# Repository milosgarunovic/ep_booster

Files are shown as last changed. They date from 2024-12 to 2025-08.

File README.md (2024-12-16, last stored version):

# ep_booster

KiCad project for EP Booster

---

The idea with this project is to have it in one place, with some "standards" like to view everything
in KiCad and export for manufacturing.

As a bassist, I'm using EP Booster as always on pedal in vintage mode without a boost, and it gives
a nice warmth to my custom bass with jazz pickups, and better thump with my Squier VM Precision with
Wilde P-46 pickup.

What I want to do as a first version is to have the whole thing as a pedal, and then strip away the
parts that are for boost and just leave the vintage part in there so I can put it into my basses,
thus removing one pedal from signal chain.

---

Resources for the project:

- https://www.taydakits.com/instructions/ep-booster/pages/designators-and-components--20
- https://revolutiondeux.blogspot.com/2012/01/xotic-ep-booster.html
- http://toshi.life.coocan.jp/review/en_diy_booster_surface_mount.html
- https://www.amp-fx.de/ep-preamp-booster-en.htm (this one is interesting because it has more caps to change the
  characteristic of the vintage mode)
- https://guitar-electronics.eu/en_US/p/EP-BOOSTER-kit-ULTRA/408

---

From the first source, here's the BOM

## Capacitors (POLYESTER FILM BOX TYPE CAPACITOR)

- C1 47NF 100V 5% POLYESTER FILM BOX TYPE CAPACITOR
- C5 3.3NF 100V 5% POLYESTER FILM BOX TYPE CAPACITOR

## Capacitors (ELECTROLYTIC CAPACITOR 5X11MM)

- C2 10UF 50V ELECTROLYTIC CAPACITOR 5X11MM
- C3 10UF 50V ELECTROLYTIC CAPACITOR 5X11MM (Original)
- C3 0.1UF 50V ELECTROLYTIC CAPACITOR 5X11MM  (Remove more bass)
- C6 10UF 50V ELECTROLYTIC CAPACITOR 5X11MM
- C7 10UF 50V ELECTROLYTIC CAPACITOR 5X11MM
- C8 47UF 25V ELECTROLYTIC CAPACITOR 5X11MM

## Capacitors (ELECTROLYTIC CAPACITOR 6X11MM)

- C4 100UF 35V ELECTROLYTIC CAPACITOR 6X11MM

## Diode

- D1 1N4148 1N4148 SWITCHING SIGNAL DIODE

## Transistors

- Q1 J201 SMD SOT-23 J201 JFET N-CHANNEL TRANSISTOR
- Q2 2N5088 2N5088 GERENAL PURPOSE TRANSISTOR

## Resistors

- R1 1M OHM 1/4W 1% METAL FILM RESISTOR
- R2 33K OHM 1/4W 1% METAL FILM RESISTOR
- R3 1M OHM 1/4W 1% METAL FILM RESISTOR
- R4 50k Trimmer 50K TRIMMER POTENTIOMETER
- R5 4.7K OHM 1/4W 1% METAL FILM RESISTOR
- R6 1K OHM 1/4W 1% METAL FILM RESISTOR
- R7 15K OHM 1/4W 1% METAL FILM RESISTOR  (Original)
- R7 33K OHM 1/4W 1% METAL FILM RESISTOR  (Remove more treble)
- R8 10K OHM 1/4W 1% METAL FILM RESISTOR
- R9 1M OHM 1/4W 1% METAL FILM RESISTOR
- R10 10K OHM 1/4W 1% METAL FILM RESISTOR
- R11 10K OHM 1/4W 1% METAL FILM RESISTOR
- R12 47K OHM 1/4W 1% METAL FILM RESISTOR
- R13 100 OHM 1/4W 1% METAL FILM RESISTOR

## Potentiometer

- GAIN 10k-C 10K OHM ANTI-LOG POTENTIOMETER

## Switches

- S1 (Bass) - MINI SLIDE SWITCH SPDT ON-ON (Vintage?)
- S2 (Treble) - MINI SLIDE SWITCH SPDT ON-ON (Bright?)

BIAS

Adjust R4 for biasing. The original value of R4 is 8.2k Ohm.

MODIFICATIONS

The original bass and treble switches do not have noticeable effect. To remove more bass, reduce C3 capacitance (e.g.
0.1 uF). To remove more treble, increase R7 resistance (e.g. 33k).

SWITCHES

The PCB allows to mount 4.7mm pitch switches inside the enclosure.

S1 (Bass)       MINI SLIDE SWITCH SPDT
S2 (Treble)     MINI SLIDE SWITCH SPDT

If no switches are required, no need to mount C4 and R7.

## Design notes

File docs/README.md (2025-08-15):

# EP Booster

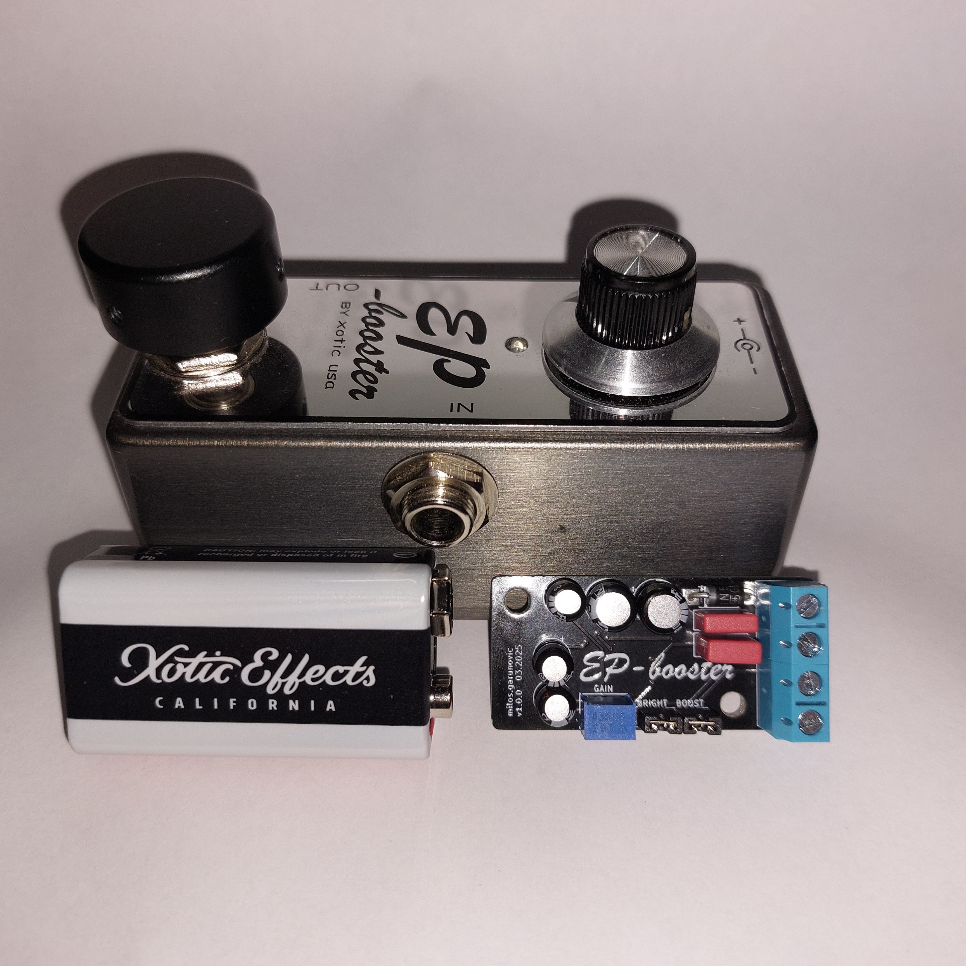
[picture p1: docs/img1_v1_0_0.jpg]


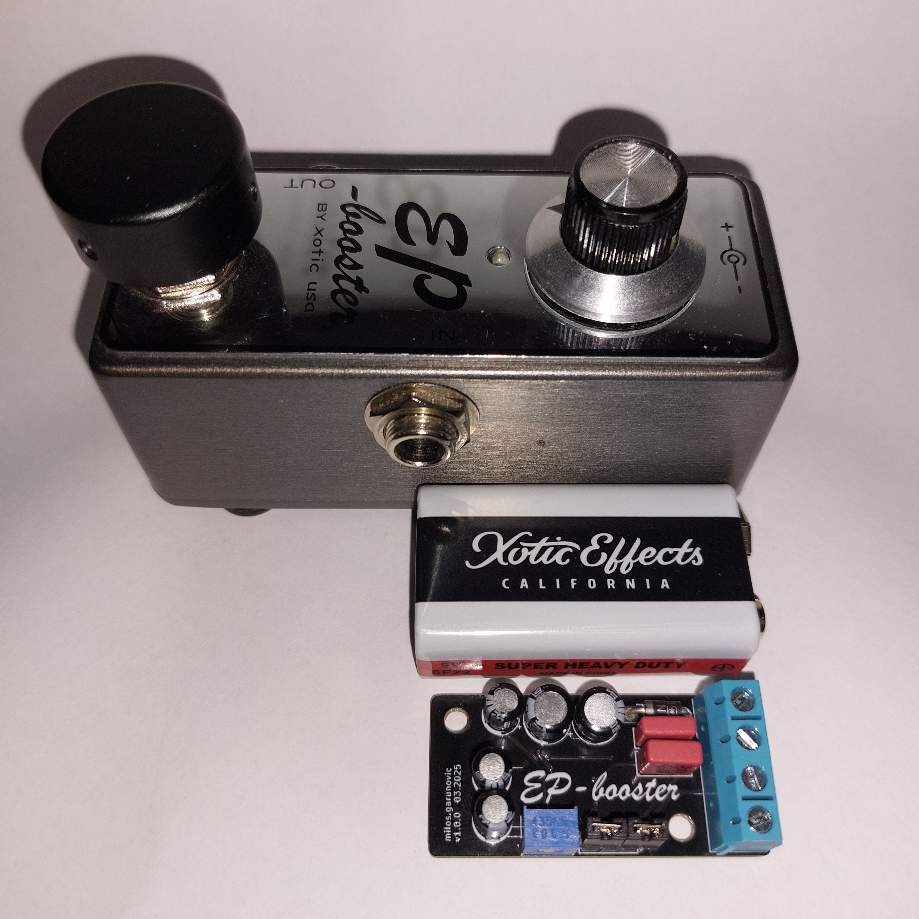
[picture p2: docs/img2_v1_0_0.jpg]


---

The idea with this project is to have everything on one place, with some "standards" like to view everything in KiCad
and export for manufacturing.

As a bassist, I'm using EP Booster as always on pedal in vintage mode without a boost, and it gives a nice warmth to my
custom bass with jazz pickups, and better thump with my Squier VM Precision with Wilde P-46 pickup.

Since I already have the pedal, first version will actually be ready to put into the bass, so it will use a trim pot,
but that can be wired onto a 10k pot if you want to have an "interface" to boost.

I guess the battery for eq part will last a long time in bass, since I was running it as a pedal for 3-4 months as
always-on on battery, and with stripped components (especially LED), it should last even longer. I'll have to do
measurements and write that here.

---

## Usage

If you want Vintage mode (like me) without a boost, use 10K resistor instead of the trim pot, and you can leave out male
pin headers, this will make sure +3dB is off and vintage mode is on.

I've made just the first board with that, so I can test it, but my plan was to use it without boost and with vintage
mode on so next ones I solder will be without those two components, and I'll just put 10K resistor there.

Use two jumper connectors to connect pin headers for bright/boost.

---

## Decisions

Why this board uses pin header connectors:

1. It's cheaper than a switch
2. Smaller footprint (in mm²), which is important in a board this compact
3. The pedal will be used probably how you set it up once, so you won't change that

The only benefit of a switch is that it's more practical, and you won't lose jumper shunt. But since I soldered it only
on the first board, and I'm not planing to use that anyway, I won't solder it anymore.

---

Resources for the project:

- https://aionfx.com/news/tracing-journal-xotic-ep-booster-v2/ (the pedal I've made is 100% based on this)
- https://www.taydakits.com/instructions/ep-booster/pages/designators-and-components--20
- https://revolutiondeux.blogspot.com/2012/01/xotic-ep-booster.html
- http://toshi.life.coocan.jp/review/en_diy_booster_surface_mount.html
- https://www.amp-fx.de/ep-preamp-booster-en.htm (this one is interesting because it has more caps to change the
  characteristic of the vintage mode)
- https://guitar-electronics.eu/en_US/p/EP-BOOSTER-kit-ULTRA/408

---

I've copied the AionFx to KiCad but without R15 and LED1 since I'm not planning to put that into the bass, but that
can be added later, and we can just bypass it or leave the components out, or rather not use it. I hope that won't
affect tone because it might lower the voltage a bit. I'll test with my pedal to see if there's any difference and make
changes to the schematic if necessary, but I don't need LED so if it does lower voltage and affects tone, I'll have to
find a workaround.

Since I'll be using trimmer instead of potentiometer, it doesn't matter if it's audio/linear/log/reverse audio, I'm
planning to keep the gain at the lowest value anyway (so highest value cap - 10kOhm), so it works without a boost. But
if a signal from bass is weak, it can serve as a boost to get hotter signal out of the bass. This will consume more
battery.

---

[Here's more info about EP Booster Vintage mode.](ep_booster_info.md)

---

TODO:

1. ✅ Make 3D case that should be the same size as battery, so positioning can be like two batteries one next to other,
   but should keep in mind the switches and pot, they should be available for easy modification.
2. ✅ Add bypass switch, so it's easy to bypass on low battery. This can even be soldered to push/pull pot
3. Add LED and current limiting resistor R15 to the schematic so it's complete, but it doesn't have to be on the board
4. Experiment with different capacitor values like the one from amp-fx, to see if there's anything better or is it maybe
   per bass better
5. ✅ Voltage doubler combined with EP booster for more headroom. Maybe put a switch there so you can choose if you want
   to use 9 or 18v.
   Schematic is made and I have it working, it produces 17.5v. I'll create a separate scheme for it, I don't think
   there's a need to use 18v onboard. The sound is there and there's probably plenty of gain. I didn't measure that yet.
6. test how much boost I get from every 1K resistence, or if there's like 16db boost, measure when I get every
   -1 db so I can say for example I want exactly 10db boost. Also test with 18V battery since it has bigger headroom.
   Test when I have +3db boost on as well, is it really 3db or what. Test db output in bypass and switched on without
   any boost to see if there is in fact any boost because my ears say there is.
7. See if it's possible to make it work on a 3 way switch, with positions off, on without boost (10k resistor), on with
   boost (some resistance, maybe that should stay on trim pot)
8. Replace C2 from 47uF to 10uF. I've opened my EP Booster and checked for value of C7 (my C2) and saw that it wasn't
   47uF but 12uF (10uF +- 20% tolerance). Why I noticed this is because images from aixon tracing show six of the same
   caps and one different. The six are red ones from Jackcon (35V -40 to 105 degrees C, 5mm wide, 7.2mm high, 2.5mm
   lead spacing). So I guess that's the only part to change and test if it works the same as original.

---

From tadyakits - worth experimenting for sound change

The original bass and treble switches do not have noticeable effect. To remove more bass, reduce C3 capacitance (e.g.
0.1 uF). To remove more treble, increase R7 resistance (e.g. 33k).

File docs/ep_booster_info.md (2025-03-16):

# EP Booster Info

This is something I've found online, and I'd like to keep everything in one place so if anyone is interested in the
vintage mode, below you can find more about it.

---

https://forum.fractalaudio.com/threads/ep-booster-effect.123258/post-1466546

2007
"There was a recent post about how an EP-3 preamp sounds good. I had a look at the schematic and couldn't see how such a
simple circuit could make any difference, so I built myself a copy of the preamp to try.

Sure enough, the preamp added a bit of "body" or "roundness" to the guitar tone, but I still couldn't see why. I checked
with an oscilloscope and couldn't see any EQ effect or any amplitude distortion. Finally, it occurred to me to check
phase difference between input and output by triggering the scope from the input only.

Again, sure enough, there was some phase distortion. At some frequencies, the output phase was leading the input phase,
and at other frequencies, the opposite occurred.

It's been established for a long time that the human ear uses phase relationship between sounds to determine direction
of sounds. I suspect that varying phase between frequencies in the same sound may cause the brain to perceive an effect
that is similar to EQ."

2010
"Boost is in the 4KHz to 6KHz region in the EP-PRE. The fact that harmonics at 6KHz lag 1KHz signal components by about
30 degrees does appear to have a significant effect on perceived
levels." [note: this last statement refers to phase response]

2012
"...the frequency response curve is surprisingly flat, with only a gentle roll-off of high frequencies (less than 3db at
6KHz) and an even gentler roll-off of low frequencies.
The key to the EP-3 and EP-PRE sound is phase response. The phase of low frequencies is advanced and the phase of higher
frequencies is delayed. Real world sounds such as guitar sound contain a fundamental frequency and a number of
harmonics, multiples of the fundamental. The fundamental of an open high E string is 330Hz, but when you pick the
string, the resulting sound will contain varying amounts of 660Hz, 990Hz, 1320Hz etc. The higher frequency harmonics
will be phase delayed. The phase relationship between the fundamental and harmonics can carry spatial information. This
phenomenon has been used for many years to create convincing "surround sound" in little boom boxes that have only two
speakers."

2013
"The EP-3 preamp has very little effect on frequency response, maybe a little extreme bottom end roll-off and, at the
other end, a mild top roll-off.

Phase response is another story, and it is phase response that creates the almost undefinable magic tone of the preamp.
The special phase response of the circuit can add top end sparkle, in spite of the top roll-off. The effect can vary
when used in conjunction with other gear that adds its own non-linearity to signal phase."

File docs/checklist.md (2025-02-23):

# Checklist

## Schematic design

- [x] Setup
    - [x] Set grid
    - [x] Page settings (TODO revise date on date of release)
- [x] Symbols
    - [x] Add symbols to the sheet
    - [x] Create symbols if needed
    - [x] Add values to symbols (Component values)
- [x] Arrange, annotate, associate
    - [x] Arrange symbols in functional blocks
    - [x] Annotate symbols
    - [x] Associate with footprints
- [x] Wire
    - [x] Signals
    - [x] Power (PWR_FLAG)
- [x] Nets
    - [x] Set net names
- [x] Electrical Rules Check
    - [x] Run ERC
    - [x] Fix errors
    - [x] Repeat ERC
- [x] Comments
    - [x] Add text information (group component in boxes, add comments)
    - [x] Add graphics

## Layout design

- [x] Setup
    - [x] Set grid
    - [x] Set design rules (check manufacturer for constraints for minimum values)
    - [x] Import footprints from schematic
- [x] Outline and constrains
    - [x] Define size and shape (Edge.Cuts layer)
    - [x] Define mounting holes
    - [x] Define cutouts
- [x] Footprints
    - [x] Place components on board
    - [x] Arrange user interface components
    - [x] Arrange in functional blocks
    - [x] Complete placement
- [x] Route
    - [x] Critical traces
    - [x] Power
    - [x] Copper fills
    - [x] Everything else
- [x] Silkscreen (F.Silkscreen and B.Silkscreen layers)
    - [x] Add text information (reference designators, functionality text (boost, gain, bright...))
    - [x] Add graphics (name, personal logo/name, version)
- [x] Design rules check
    - [x] Run DRC
    - [x] Fix errors
    - [x] Repeat DRC
- [ ] Export & Manufacture
    - [ ] Create Gerber files
    - [ ] Verify Gerber files
    - [ ] Upload Gerber files to manufacturer

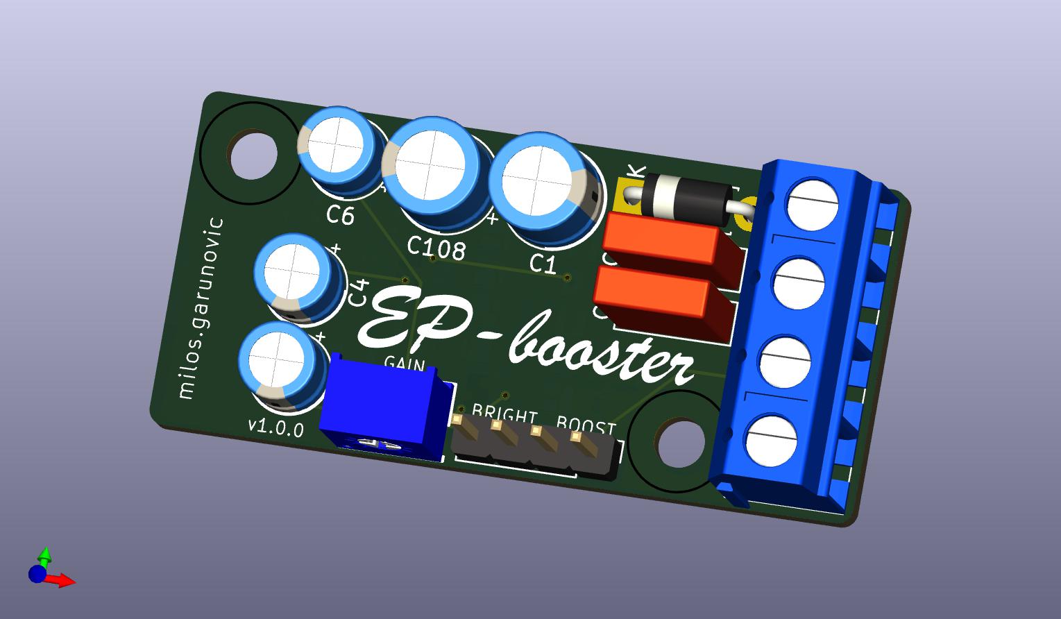
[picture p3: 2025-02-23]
docs/ep_booster_v1_0_0.jpg

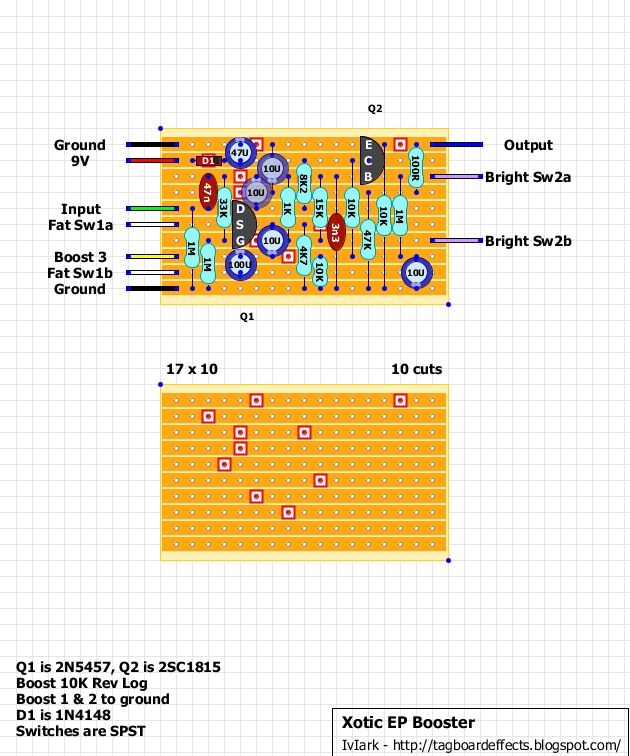
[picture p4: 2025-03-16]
docs/Xotic EP Booster.png

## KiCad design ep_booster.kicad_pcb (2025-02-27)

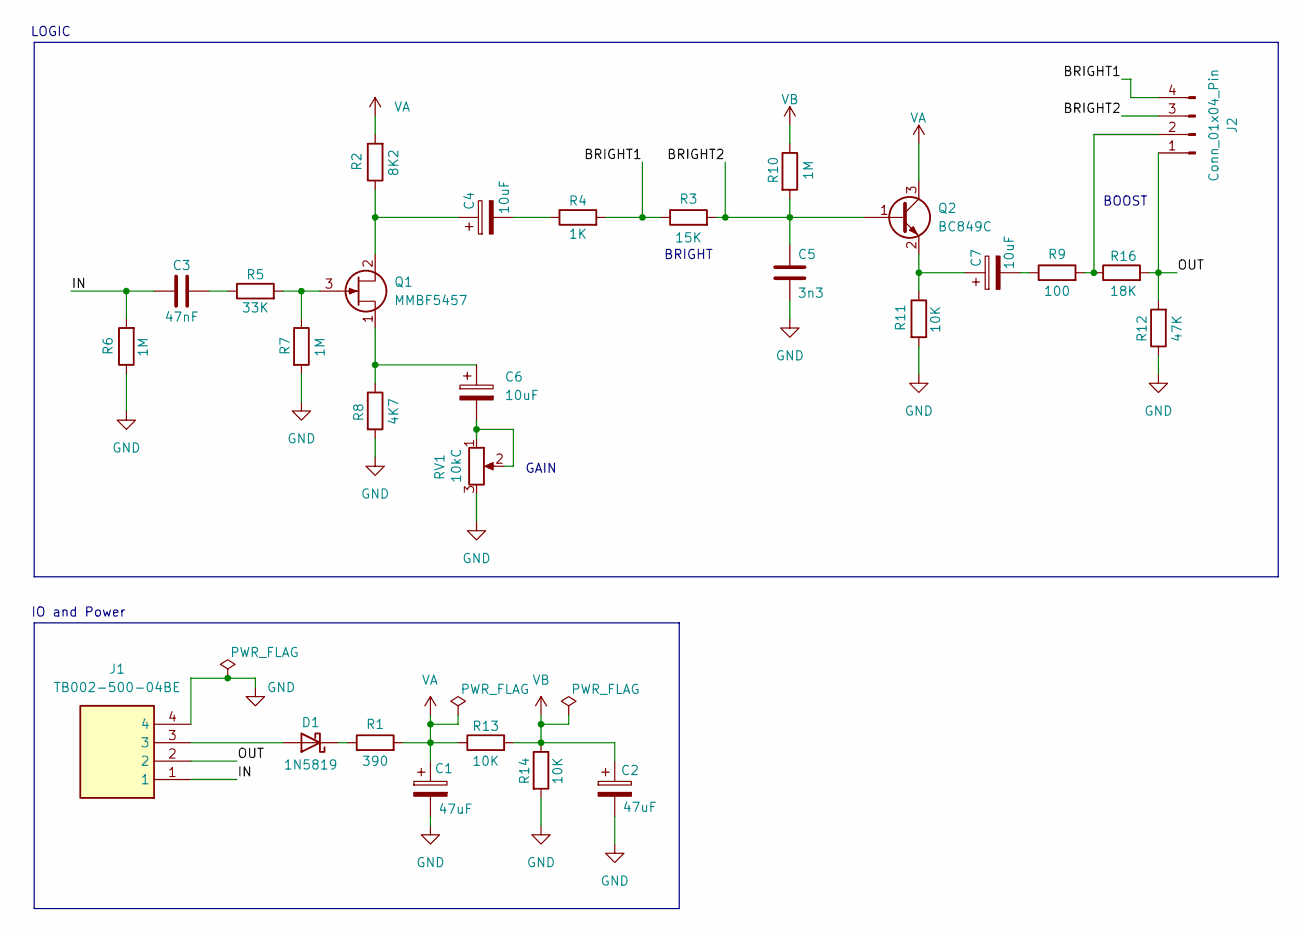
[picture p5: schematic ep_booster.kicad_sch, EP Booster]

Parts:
C1, C2: 47uF; CP_Radial_D6.3mm_P2.50mm
C3: 47nF; C_Rect_L7.2mm_W2.5mm_P5.00mm_FKS2_FKP2_MKS2_MKP2
C4, C6, C7: 10uF; CP_Radial_D5.0mm_P2.50mm
C5: 3n3; C_Rect_L7.2mm_W3.0mm_P5.00mm_FKS2_FKP2_MKS2_MKP2
D1: 1N5819; D_DO-41_SOD81_P7.62mm_Horizontal
J1: TB002-500-04BE; TB00250004BE; Mouser Part Number 490-TB002-500-04BE
J2: Conn_01x04_Pin; PinHeader_1x04_P2.54mm_Vertical
Q1: MMBF5457; SOT-23
Q2: BC849C; SOT-23
R1: 390; R_1206_3216Metric_Pad1.30x1.75mm_HandSolder
R2: 8K2; R_1206_3216Metric_Pad1.30x1.75mm_HandSolder
R3: 15K; R_1206_3216Metric_Pad1.30x1.75mm_HandSolder
R4: 1K; R_1206_3216Metric_Pad1.30x1.75mm_HandSolder
R5: 33K; R_1206_3216Metric_Pad1.30x1.75mm_HandSolder
R6, R7, R10: 1M; R_1206_3216Metric_Pad1.30x1.75mm_HandSolder
R8: 4K7; R_1206_3216Metric_Pad1.30x1.75mm_HandSolder
R9: 100; R_1206_3216Metric_Pad1.30x1.75mm_HandSolder
R11, R13, R14: 10K; R_1206_3216Metric_Pad1.30x1.75mm_HandSolder
R12: 47K; R_1206_3216Metric_Pad1.30x1.75mm_HandSolder
R16: 18K; R_1206_3216Metric_Pad1.30x1.75mm_HandSolder
RV1: 10kC; 3362S1103LF

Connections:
/BRIGHT1: J2.4, R3.1, R4.2
/BRIGHT2: C5.1, J2.3, Q2.1 (B), R3.2, R10.2
/IN: C3.1, J1.1, R6.2
/OUT: J1.2, J2.1, R12.2, R16.2
GND: C1.2, C2.2, C5.2, J1.4, R6.1, R7.2, R8.2, R11.2, R12.1, R14.2, RV1.3
unnamed: C3.2, R5.1
unnamed: C4.2, R4.1
unnamed: C6.2, RV1.1, RV1.2
unnamed: C7.2, R9.1
unnamed: D1.2 (A), J1.3
unnamed: D1.1 (K), R1.1
unnamed: J2.2, R9.2, R16.1
unnamed: C4.1, Q1.2 (D), R2.1
unnamed: Q1.3 (G), R5.2, R7.1
unnamed: C6.1, Q1.1 (S), R8.1
unnamed: C7.1, Q2.2 (E), R11.1
VA: C1.1, Q2.3 (C), R1.2, R2.2, R13.1
VB: C2.1, R10.1, R13.2, R14.1

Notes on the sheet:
BOOST
BRIGHT
GAIN
IO and Power
LOGIC

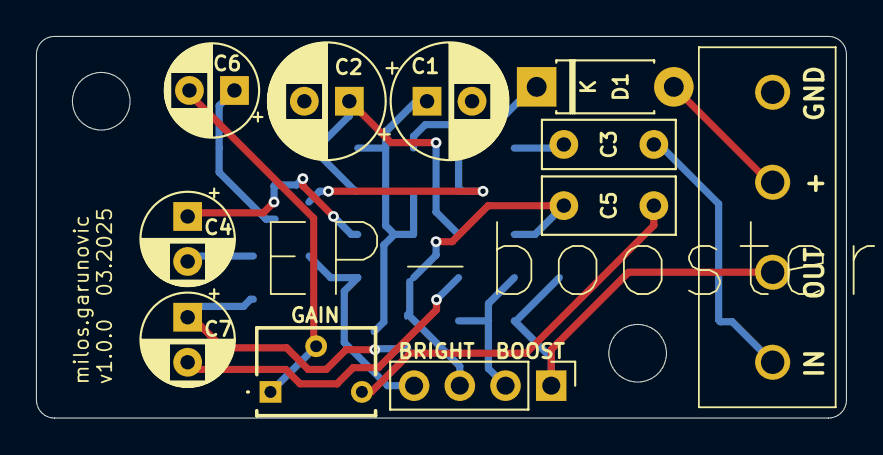
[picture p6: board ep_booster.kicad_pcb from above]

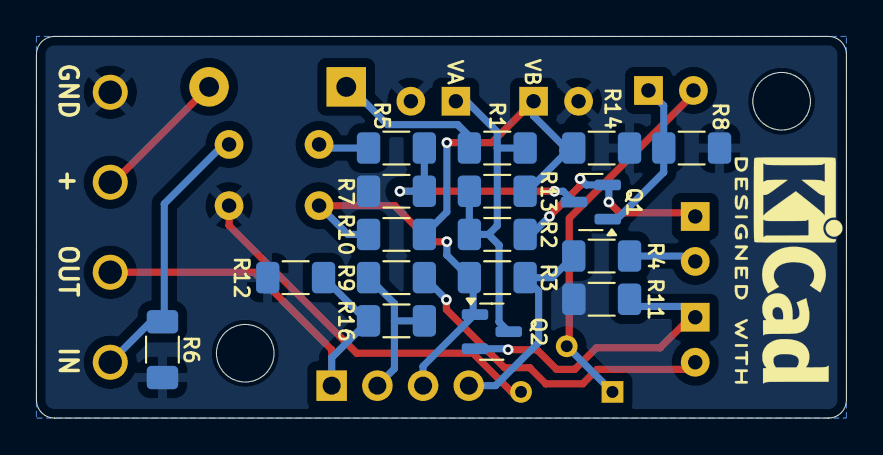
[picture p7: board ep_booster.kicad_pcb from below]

Board: 2 copper layers, 45.0 x 21.2 mm, 28 parts (17 on the bottom side), 18 nets.

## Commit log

2024-12-16 updated readme and added initial kicad files
    [ep_booster.kicad_pcb, ep_booster.kicad_sch]
2024-12-16 schema added
    [ep_booster.kicad_sch]
2025-01-05 traced board from aionfx
    [ep_booster.kicad_sch]
2025-01-06 footprint association
    [ep_booster.kicad_sch]
2025-01-31 libs and pcb design update
    [ep_booster.kicad_pcb, ep_booster.kicad_sch]
2025-02-03 libs and pcb design update (2)
    [ep_booster.kicad_pcb, ep_booster.kicad_sch]
2025-02-03 changed pot to bourns 3362S
    [ep_booster.kicad_pcb, ep_booster.kicad_sch]
2025-02-03 component placement update
    [ep_booster.kicad_pcb]
2025-02-23 schematic design finished according to checklist
    [ep_booster.kicad_sch]
2025-02-23 added 9v battery outline on User.1 layer for reference
    [ep_booster.kicad_pcb]
2025-02-23 refactored layout and added 2 mounting holes for M3 screws
    [ep_booster.kicad_pcb]
2025-02-23 replaced two 1x02 pin headers with 1x04
    [ep_booster.kicad_pcb, ep_booster.kicad_sch]
2025-02-23 tracing and copper field (GND) added
    [ep_booster.kicad_pcb]
2025-02-23 silkscreen f and b done
    [ep_booster.kicad_pcb]
2025-02-23 silkscreen text and graphics + docs update
    [ep_booster.kicad_pcb]
2025-02-23 added board dimensions on User.1 layer and 3D image to docs
    [ep_booster.kicad_pcb]
2025-02-25 C5 updated footprint 2.5->3mm width
    [ep_booster.kicad_pcb]
2025-02-27 increase track width to minimum 0.3mm, add VA and VB debug silkscreen
    [ep_booster.kicad_pcb]
2025-02-27 B.Silkscreen thickened and aligned better
    [ep_booster.kicad_pcb]
2025-02-27 increase track width to 0.4mm
    [ep_booster.kicad_pcb]
2025-02-27 add F.Silkscreen for IO, update C ref des
    [ep_booster.kicad_pcb, ep_booster.kicad_sch]
2025-02-27 finalizing updates
    [ep_booster.kicad_pcb]
2025-02-27 gerber export (kicad plugin)
